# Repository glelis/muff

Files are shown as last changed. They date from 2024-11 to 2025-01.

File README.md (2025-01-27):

# MUFF: Motorized Positioner for Multi-Focus and Photometric Stereo Imaging

This repository contains the resources and documentation for the **MUFF** project, a low-cost motorized positioner designed to facilitate the acquisition of multi-focus and photometric stereo images of millimeter-scale objects. 

Developed primarily using **3D printing** and **Arduino**, MUFF automates the process of capturing images under varying focus planes and illumination conditions, enabling enhanced 3D object reconstruction.

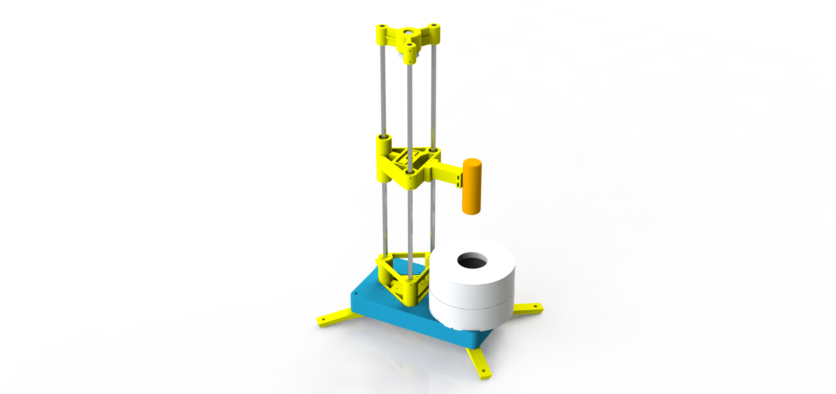
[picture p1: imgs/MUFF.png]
Automated Positioner


## Features
- **Multi-Focus Stereo (MFS)**: Combines images at different focus levels into a single sharp composite image.
- **Photometric Stereo (PMS)**: Captures and analyzes surface details under varied lighting conditions to recover 3D shape information.
- **Automation**: Motorized positioning with sub-millimeter precision and up to 24 independent lighting conditions.
- **Affordable Design**: Built using 3D-printed components and readily available hardware.
- **Flexible Operation**: Controlled via an Arduino Nano microcontroller and a Python-based interface.

## Components
- **Hardware**: 
  - 3D-printed structural and mechanical parts.
  - Stepper motor and threaded rod for vertical displacement.
  - Adjustable light box with 24 LED sources.
- **Electronics**:
  - Arduino Nano for motion and lighting control.
  - DRV8825 motor driver and custom PCB for system integration.
- **Software**:
  - Arduino firmware for precise control of the positioner.
  - Python script for image acquisition and user interaction.

## Applications
MUFF is ideal for:
- Optical microscopy
- Imaging in fields like paleontology, petrology, manufacturing, and archaeology
- Low-power microscopy for small-scale object analysis

## Citation
If you use MUFF in your research or projects, please consider citing our work:

## Paper Link
[Paper](https://www.researchgate.net/publication/358866260_MUFF_A_Low-cost_Motorized_Positioner_Developed_by_Additive_Manufacturing_to_Obtain_Multi-focus_Images)

## Acknowledgments
This project was developed by **Gustavo Lelis da Silva**, **Jorge Stolfi**, and **Helena Cristina da Gama Leitão** in collaboration with UNICAMP and UFF, with funding from CNPq, FAPERJ, and FAPESP.

For detailed documentation and additional resources, visit the [official project page](http://www.ic.uff.br/~hcgl/Muff-index.html).

---

**Keywords**: Optical Microscopy, 3D Printing, Stereo Multifocus, Photometric Stereo, Arduino

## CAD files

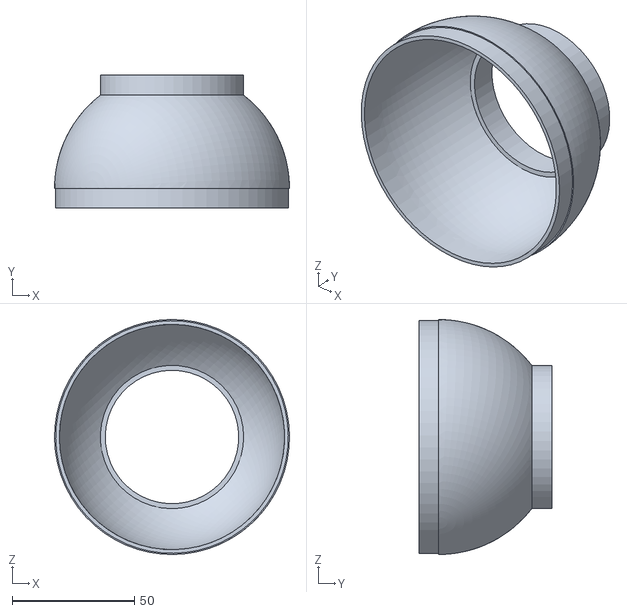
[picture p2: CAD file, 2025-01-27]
muff_stl/Palco/difusor_palco.STL
96.0 x 54.2 x 96.0

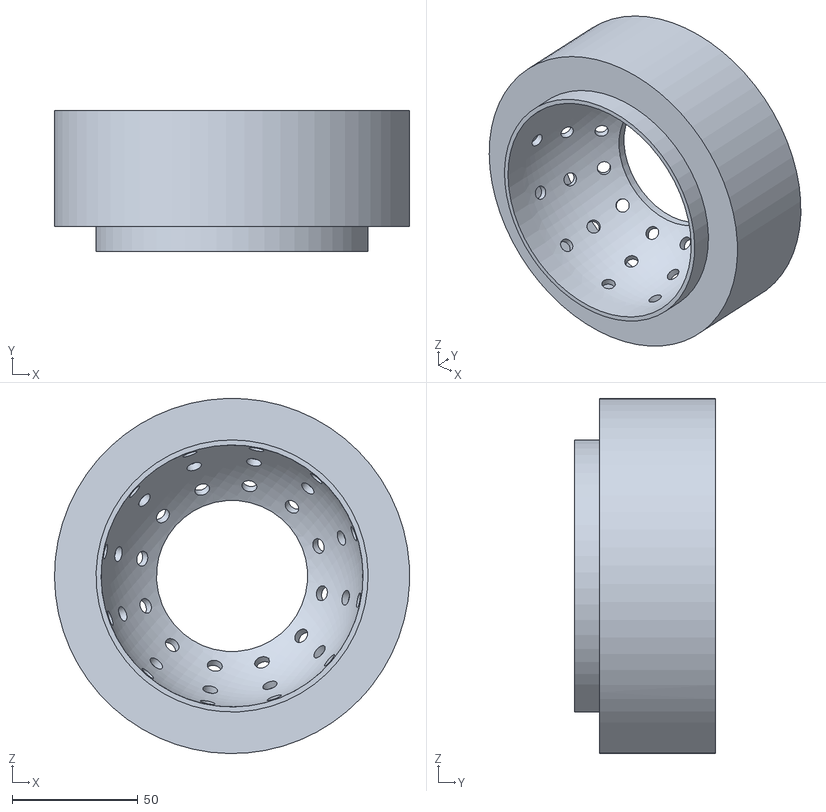
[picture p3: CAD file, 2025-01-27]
muff_stl/Palco/capa_palco.STL
140.9 x 56.1 x 140.9

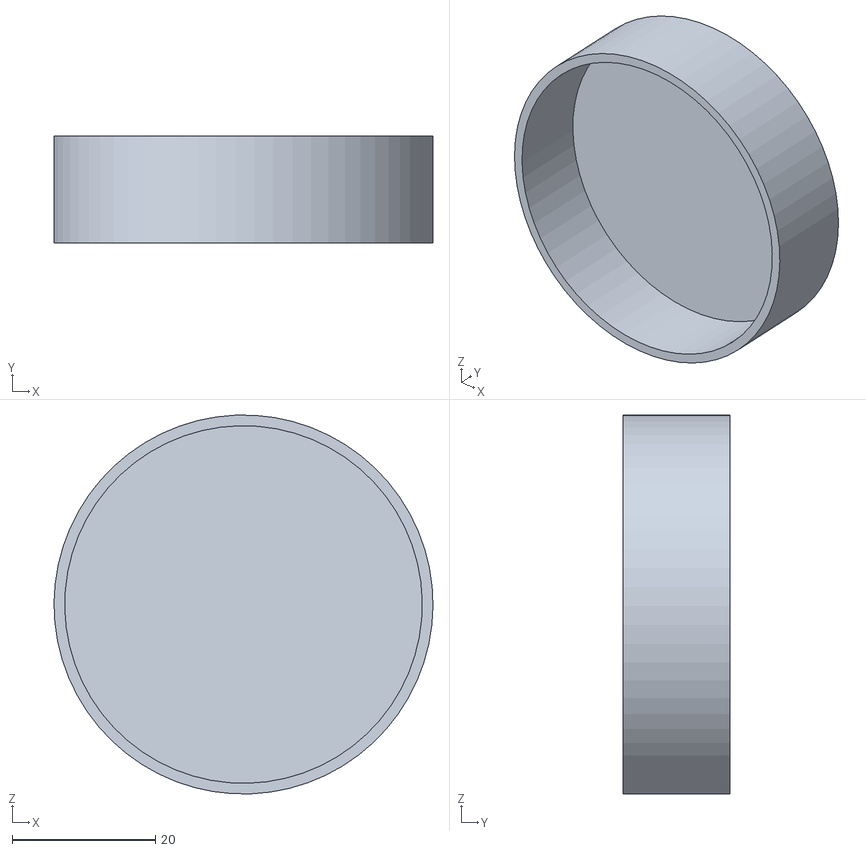
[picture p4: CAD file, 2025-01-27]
muff_stl/Palco/palco_palco.STL
53.0 x 15.0 x 53.0

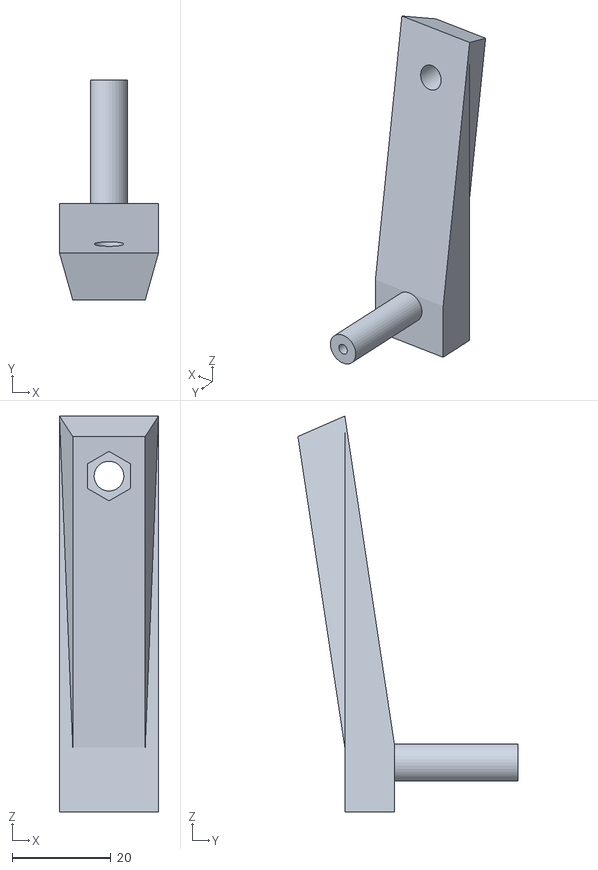
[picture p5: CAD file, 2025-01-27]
muff_stl/Posicionador/suporte.STL
20.0 x 44.5 x 80.0

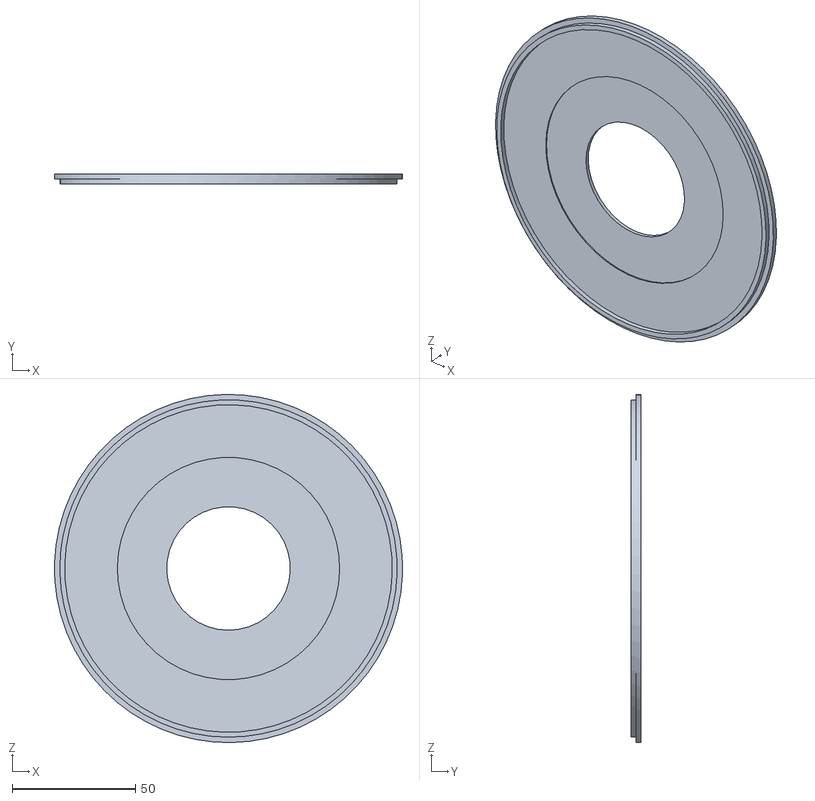
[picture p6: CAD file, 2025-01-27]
muff_stl/Palco/tampa_palco.STL
140.9 x 4.00 x 141.0

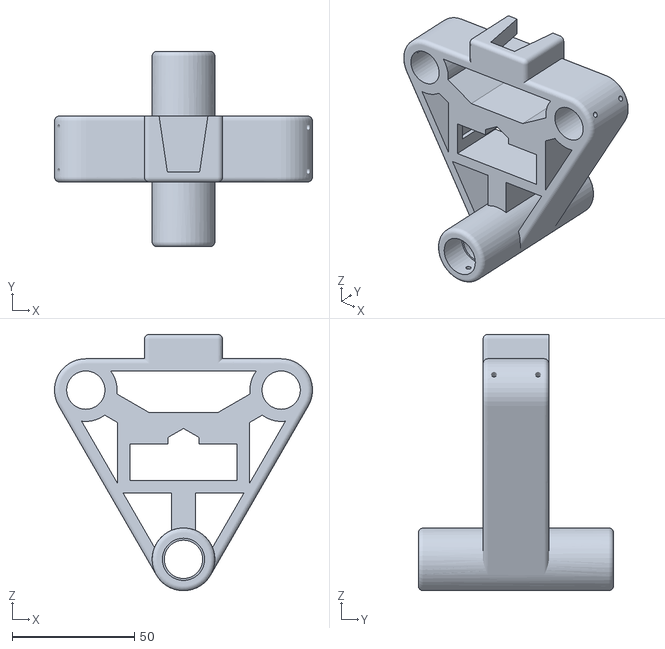
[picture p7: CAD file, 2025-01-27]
muff_stl/Posicionador/carro.STL
105.6 x 80.0 x 105.0

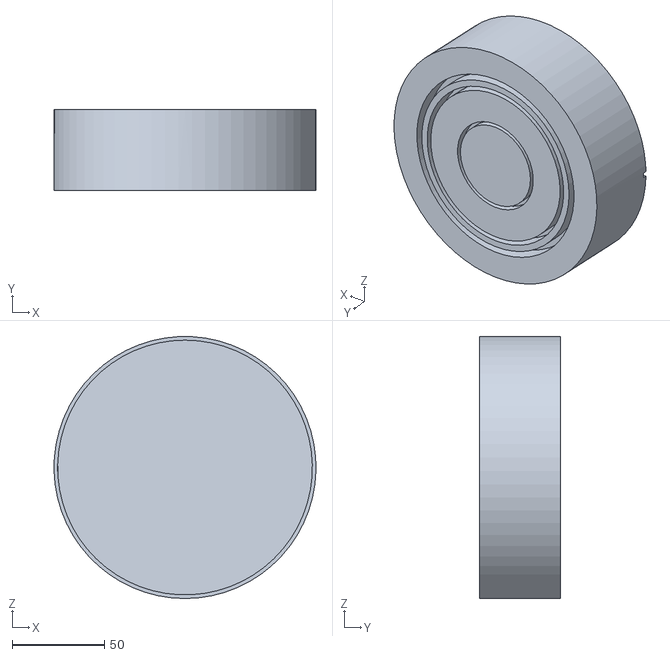
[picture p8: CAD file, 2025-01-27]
muff_stl/Palco/base_palco.STL
142.0 x 44.0 x 142.0

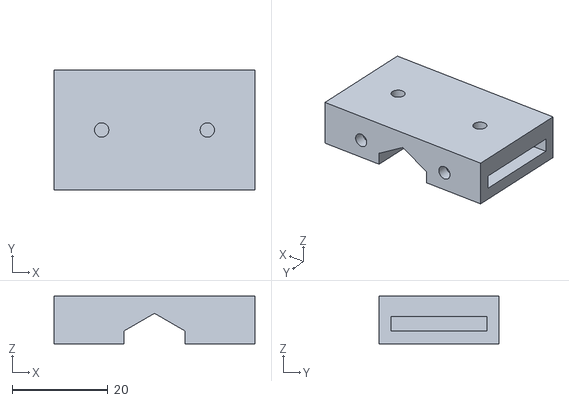
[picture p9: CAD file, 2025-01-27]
muff_stl/Posicionador/transmissao_carro.STL
42.0 x 25.0 x 10.0

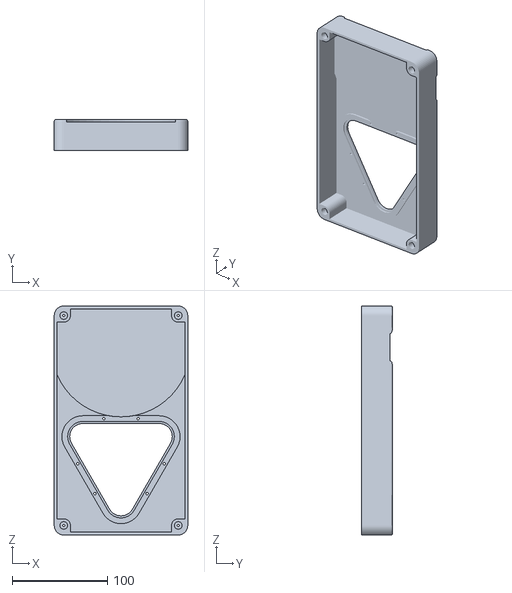
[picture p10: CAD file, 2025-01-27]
muff_stl/Posicionador/capa_base.STL
140.0 x 33.0 x 240.0

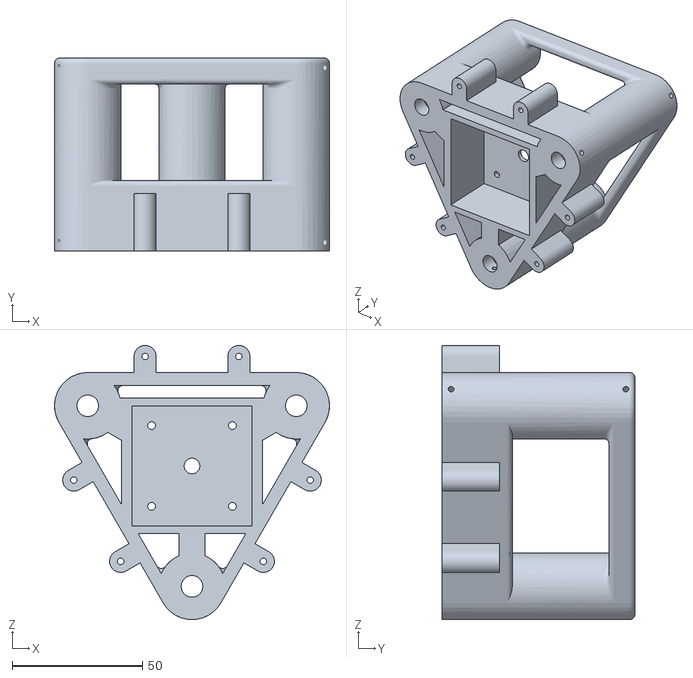
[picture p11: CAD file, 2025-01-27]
muff_stl/Posicionador/base.STL
105.5 x 74.0 x 105.2

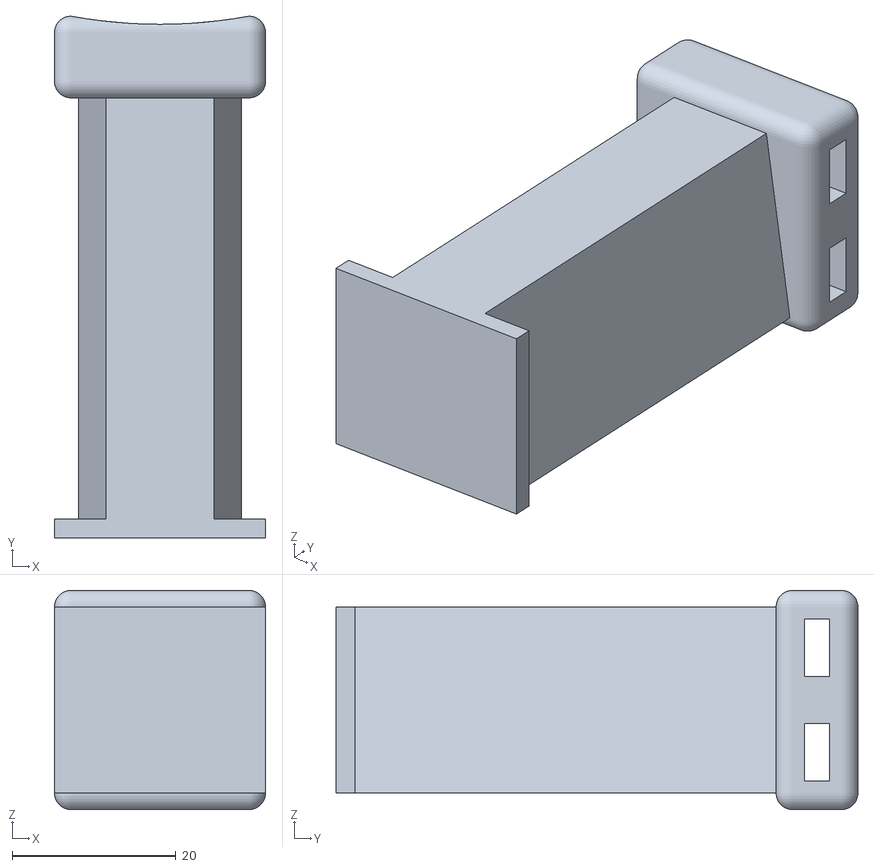
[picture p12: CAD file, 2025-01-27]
muff_stl/Posicionador/conector_microscópio.STL
25.8 x 63.8 x 26.8

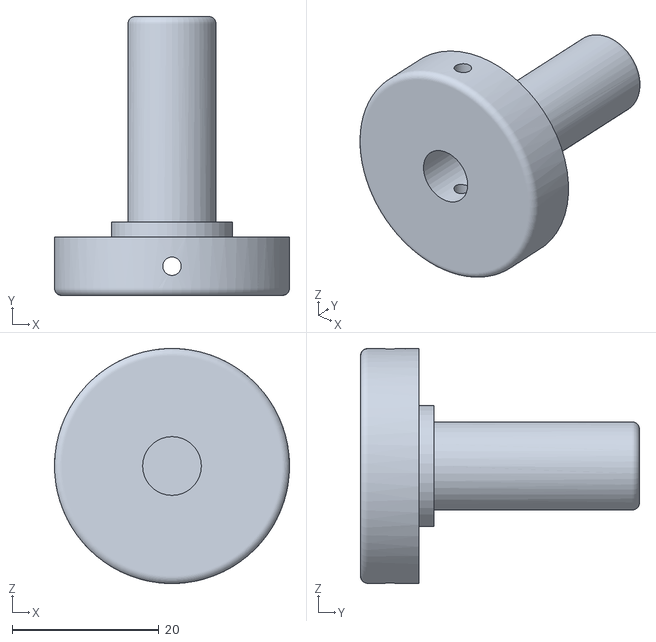
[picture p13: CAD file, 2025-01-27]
muff_stl/Posicionador/conector_superior.STL
32.0 x 38.0 x 32.0

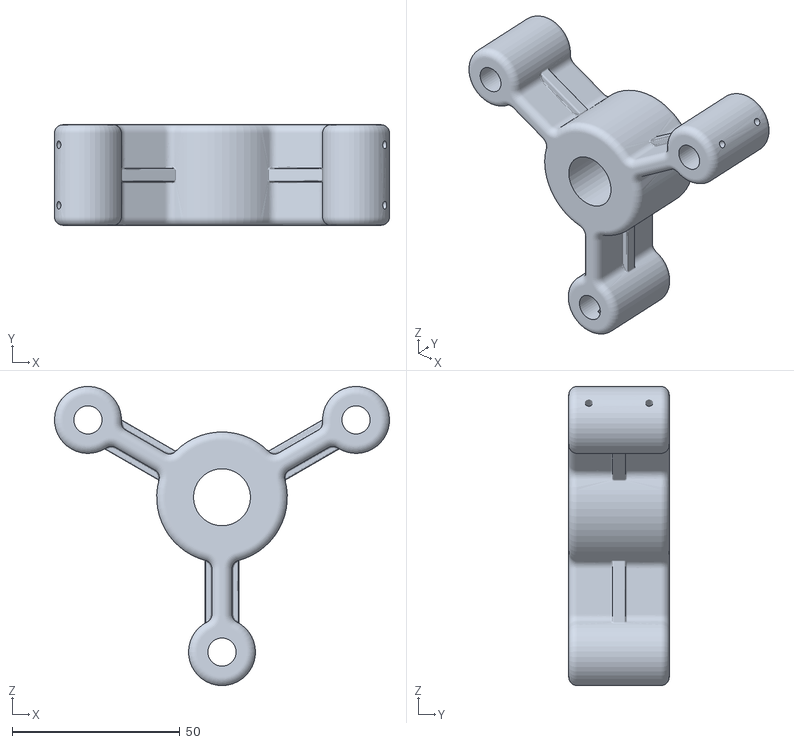
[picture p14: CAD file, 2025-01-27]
muff_stl/Posicionador/suporte_superior.STL
100.0 x 30.0 x 89.3

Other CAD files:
muff_stl/Posicionador/conector_inferior - conector inferior_2-1.STL
muff_stl/Posicionador/conector_inferior - conector inferior_2-2.STL
muff_stl/Posicionador/conector_inferior - Peça2-1.STL

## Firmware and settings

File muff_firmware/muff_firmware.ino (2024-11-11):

/* Arduino firmware for the automatic MUFF v2.0 microscope positioner. */
/* Created by Gustavo Lelis (UFF) and Jorge Stolfi (UNICAMP), 2017-2018. */
/* Last edited on 2019-01-07 18:54:47 by stolfilocal */

#include <AccelStepper.h>
#include <muff_utils.h>
#include <muff_comandos.h>

// Estado interno do firmware:

int estados_dos_leds[num_bytes_leds]; // Bytes cujos bits indicam os estados correntes dos LEDs.

// Parametros do motor de passo principal (a ajustar experimentalmente):

int motor1_max_acel = 500;   // Aceleracao maxima (passos/segundo^2).

int desloc_ajuste_fino = 30;       // Passos a deslocar nos comandos '1', '2'. 
int motor1_max_vel_fino = 80;      // Velocidade maxima no ajuste fino (passos/segundo).

int desloc_ajuste_grosso = 15000;  // Passos a deslocar nos comandos '6', e '7'. 
int motor1_max_vel_grosso = 400;   // Velocidade maxima no ajuste grosseiro (passos/segundo).

int desloc_quadro = 0;             // Passos a deslocar no comando '5', definido pelo comando '4'.
int motor1_max_vel_quadro = 400;   // Velocidade maxima do comando '5' (passos/segundo).

const int pinoChave = 10; //PINO DIGITAL UTILIZADO PELA CHAVE FIM DE CURSO

AccelStepper motor1; // Configuracao e estado do motor.

void setup()
  { inicializa_porta_serial();
  
    inicializa_leds(estados_dos_leds);
    
    motor1 = inicializa_motor1(motor1_max_acel);

    pinMode(pinoChave, INPUT_PULLUP); //DEFINE O PINO COMO ENTRADA / "_PULLUP" É PARA ATIVAR O RESISTOR INTERNO DO ARDUINO PARA GARANTIR QUE NÃO EXISTA FLUTUAÇÃO ENTRE 0 (LOW) E 1 (HIGH)

    // Prompt em caso de interacao direta com usuario
    Serial.println("# Digite comando ('1', '2', etc) e clique em ENVIAR...");
  }

void processa_comando(int comando)
  {
    mostra_comando(comando);
    if (comando == '1')
      { comando_aciona_motor(&motor1, +desloc_ajuste_fino, motor1_max_vel_fino, 0); }
    else if (comando == '2')
      { comando_aciona_motor(&motor1, -desloc_ajuste_fino, motor1_max_vel_fino, 0); }
    else if (comando == '3')
      { comando_para_motor(&motor1); }
    else if (comando == '4')
      { comando_define_desloc_quadro(&desloc_quadro); }
    else if (comando == '5')
      { comando_aciona_motor(&motor1, desloc_quadro, motor1_max_vel_quadro, 1); }
    else if (comando == '+')
      { comando_aciona_leds(1,estados_dos_leds); }
    else if (comando == '-')
      { comando_aciona_leds(0,estados_dos_leds); }
    else if (comando == '6')
      { comando_aciona_motor(&motor1, +desloc_ajuste_grosso, motor1_max_vel_grosso, 0); }
    else if (comando == '7')
      { comando_aciona_motor(&motor1, -desloc_ajuste_grosso, motor1_max_vel_grosso, 0); }
    else if (comando == '8')
      { comando_define_max_acel(&motor1_max_acel); }
    else
      { muff_erro("comando invalido");  }

    // Notifica o usuario de que ocomando foi executado:
    Serial.print('0');
  }

void loop(void)
  // Loop principal do firmware. 
  { // Gera pulsos para o motor se e como necessario:
    if (motor1.isRunning())
      { // Motor estah em movimento:
        // Serial.print('!'); Serial.print(motor1.distanceToGo());
        motor1.run();
      }
    else
      { // Motor estah parado, desligue alimentacao para poupar energia:
        motor1.disableOutputs();
      }
    // Verifica se ha comando:
    if (Serial.available() > 0) 
      { // Chegou um comando:
        int comando = Serial.read();
        processa_comando(comando);
      }

    // Para o motor em caso de acionamento do sensor fim de curso
    if(digitalRead(pinoChave) == LOW)
      { //SE A LEITURA DO PINO FOR IGUAL A LOW, FAZ
        processa_comando('2');
        delay(1000);
        processa_comando('3');
      }
  }
      

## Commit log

2024-11-11 first commit: arduino firmeware and python codes.
2025-01-27 stl files
    [base.STL, base_palco.STL, capa_base.STL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]
